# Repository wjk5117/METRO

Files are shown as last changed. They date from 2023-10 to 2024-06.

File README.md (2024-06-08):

# About
This directory contains all code implementation and hardware designs for METRO.

As a brief summary, road surface markings, like symbols and line markings, are vital
traffic infrastructures for driving safety and efficiency. However,
real-world conditions can impair the utility of existing road markings. For example, adverse weather conditions such as snow and
rain can quickly obliterate visibility.
Existing vision-free methods (e.g., mmWave, RFID) suffer from several key issues, such as
signal distortion due to the multi-path effect in high-speed scenarios
and high deployment costs. 

We propose a novel MagnETic ROad marking system (METRO)
for robust recognition of road markings at low cost and high deployability. METRO pairs (a) easily deployable passive magnetic road
markings with (b) an automotive-grade magnetic sensing framework that detects and interprets these markings. The design of
METRO addresses several real-world challenges, such as mitigating
the impact of magnetic disturbances, lowering deployment costs,
and enhancing the durability of magnetic tags. On-road field tests of
METRO demonstrate an overall accuracy of over 96% in interpreting
various road markings in adverse conditions with less cost (only
$0.17 per meter) than traditional road markings ($0.21-7.70 per meter). Our field evaluation of METRO over one month demonstrates
the practicality and robustness of METRO in real-world settings.

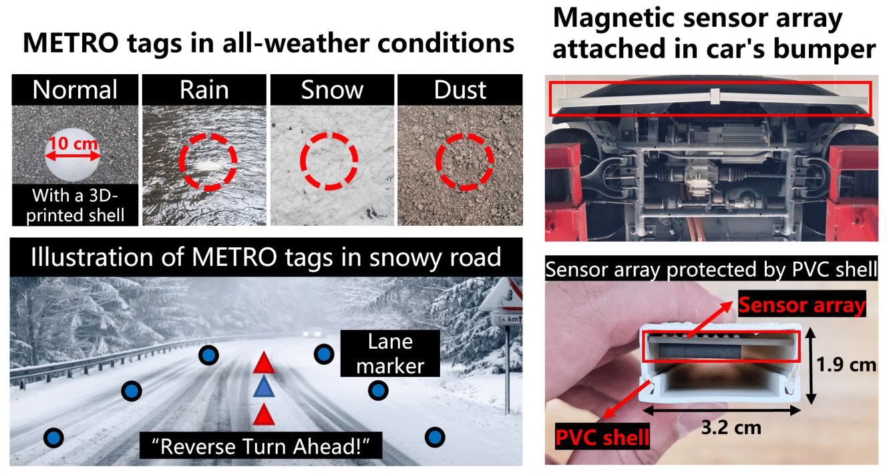
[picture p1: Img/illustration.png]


# Lisense
METRO is licensed under the MIT license included in the [LICENSE](./LICENSE) file.

# Setup
To use METRO, the following hardwares and development tools are required:
* [METRO's sensor array](#metros-sensor-array)
* [Arduino IDE](#arduino-ide-setup)
* [Python environment](#python-environment-setup)
* [PCAN-View](#connect-to-the-can-network)

## METRO's sensor array
We provide the manufacturing details of the METRO's sensor array in `/PCBs`, please see the related [README](./PCBs/README.md) file.

## Arduino IDE setup
Arduino IDE is used for programing the sensor array.

1. Download and install [Arduino IDE](https://www.arduino.cc/en/software)
2. Set up the Arduino IDE for the Teensy 4.1 Development Board, according to the [official instruction](https://www.pjrc.com/teensy/td_download.html).
Once completed, you will be able to access the board information by clicking on the 'Tools' menu
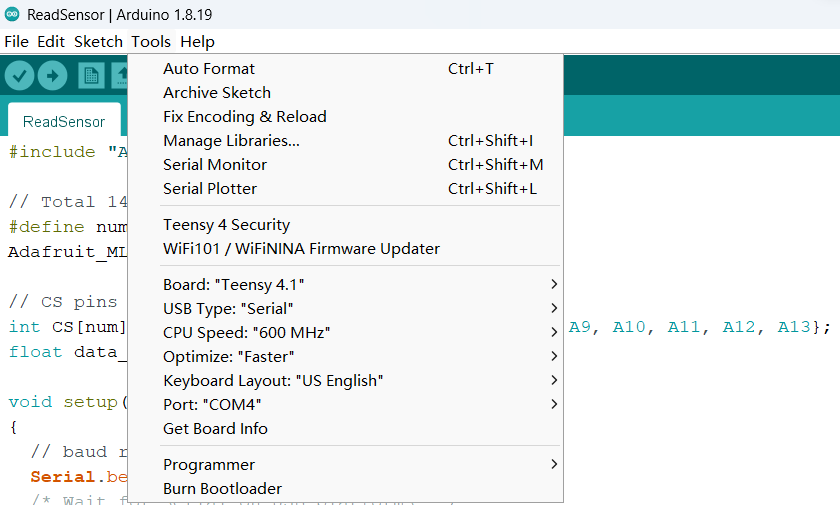
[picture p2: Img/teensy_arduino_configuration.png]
  

3. Install the Adafruit MLX90393 Library for the Arduino IDE:
    - Click 'Sketch' --> 'Include Library' --> 'Manage Libraries...'
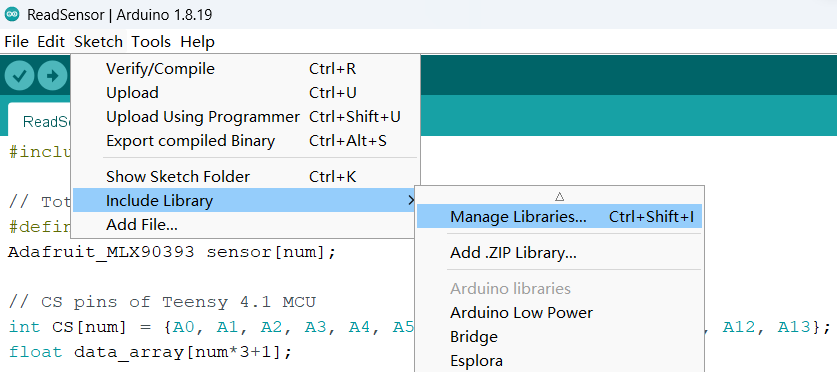
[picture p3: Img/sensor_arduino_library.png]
    
    - Search for Adafruit MLX90393, and install the Adafruit MLX90393 library:
    plot

## Python environment setup
The METRO system's sensing pipeline is developed using the Python programming language.

1. Install the Python environment. You can install the [official Python distribution](https://www.python.org/downloads/) or [Anaconda](https://www.anaconda.com/download)
2. Install all the dependencies listed in the `./Code/requirements.txt` file by using the command 'pip install \<package-name\>'.

## Connect to the CAN bus
To obtain velocity and steering angle data from the vehicle's Controller Area Network (CAN) bus,
a [PCAN-USB adapter](https://www.peak-system.com/PCAN-USB.199.0.html?&L=1) to connect to the vehicle and the official software [PCAN-View](https://www.peak-system.com/PCAN-View.242.0.html?&L=1) are required.

With these tools, you can connect to the CAN bus with the following Python script.
```python
import can
from can.bus import BusState
from can.interfaces.pcan.basic import *

BUS = can.interface.Bus(bustype="pcan",channel="PCAN_USBBUS1", bitrate=500000)
BUS.state = BusState.PASSIVE
```

Then, you can get the real-time data from the CAN network by running the following code.
```python
msg = BUS.recv(1)
```

The full implementation of obtaining velocity and steering angle data from the CAN network is integrated into the real-time sensing pipeline `Codes/Sensing_Pipeline/real_time_detecting_both_tag.py`. Please see lines 82-101 for more details.

# Run a Quick Demo
You can find a quick demo in the `/Quick_Demo` directory that does not require a connection to the vehicle's CAN network. For more information, please refer to the related [README](./Quick_Demo/README.md) file.

# Citing METRO
If you use METRO in your research or wish to refer to the baseline results, please use the provided BibTeX entry below.

```BibTex
@inproceedings{metro,
author = {Wang, Jike and Wang, Shanmu and Iravantchi, Yasha and Wang, Mingke and Sample, Alanson and Shin, Kang G. and Wang, Xinbing and Zhou, Chenghu and Chen, Dongyao},
title = {METRO: Magnetic Road Markings for All-weather, Smart Roads},
year = {2024},
isbn = {9798400704147},
publisher = {Association for Computing Machinery},
address = {New York, NY, USA},
url = {https://doi.org/10.1145/3625687.3625809},
doi = {10.1145/3625687.3625809},
booktitle = {Proceedings of the 21st ACM Conference on Embedded Networked Sensor Systems},
pages = {280–293},
numpages = {14},
keywords = {magnetic sensing, all-weather road markings, magnetometer},
location = {, Istanbul, Turkiye, },
series = {SenSys '23}
}
```

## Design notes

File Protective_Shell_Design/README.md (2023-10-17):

# 3D-printed Protective Shell Design for METRO Tags

## Description
This directory contains 3D-printed protective shell designs for the cubic passive magnet utilized in the METRO system
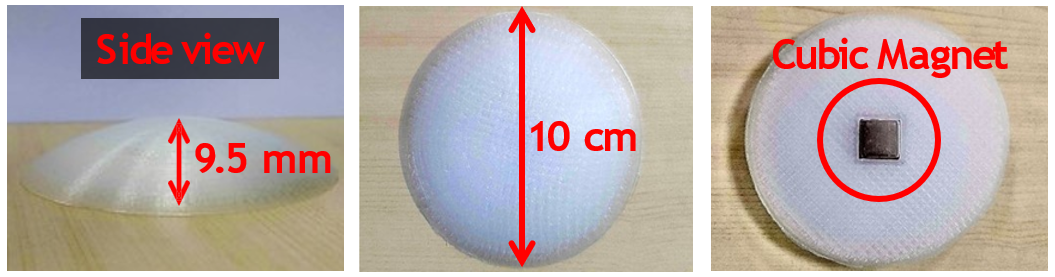
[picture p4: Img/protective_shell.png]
plot


We provide both STL (stereolithography) and G-code files for your convenience.

- line_tag.stl: The STL file for the protective shell designed for the 90-degree magnet.
- information_tag.stl: the STL file for the protective shell designed for the 0-degree magnet.
- gcode.zip: contains the G-code file for the protective shells designed for both the 90-degree magnet and 0-degree magnet.

## Design tool
We utilize [SolidWorks](https://www.solidworks.com/sw/support/downloads.htm) (version 2021) for designing all the STL files.
To convert these STL files into the G-code format, we use [Ultimaker Cura](https://ultimaker.com/software/ultimaker-cura/) (Version 5.4.0) and our 3D printer is [the Creality Ender-3 S1 Pro](https://www.creality.com/products/creality-ender-3-s1-pro-fdm-3d-printer).

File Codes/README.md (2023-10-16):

# Codes for METRO

## Arduino
- Library: Adafruit's library for the MLX90393 magnetic field sensor.
- ReadSensor: Capture time-series magnetic field data from the MLX90393 magnetometers and transmit it to the computing unit via a wired connection.

## Sensing_Pipeline
All codes for real-time detection and decoding of on-road magnetic tags.

- AMN_denoise.py: the implementation of the Adaptive Magnetic field Neutralization (AMN) algorithm to mitigate noise generated by wheel rotation.
- real_time_detecting_both_tag.py: connect to the CAN bus of a vehicle,then detect and decode both line and information tags in real time .
- real_time_detecting_info_tag.py: connect to the CAN bus of a vehicle,then detect and decode information tag in real time.
- utils.py: contains utility functions for the real-time detection process.

## Visualization
All codes for visualizing the experiment results.

## Requirements.txt
All Python package dependencies required for code execution.

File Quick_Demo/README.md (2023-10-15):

# Run a quick demo
This directory contains the code to run a quick demo of METRO.
This demo has been simplified to work without the need for a connection to the vehicle's CAN network. 

Specifically, the file `real_time_detecting_magnet.py` contains the sensing algorithm for detecting the N/S polarity of a 90-degree passive magnet.
To use this, you only need to manufacture the sensor array in  `../PCBs` and run the code using Python. 
With this setup, you can obtain real-time N/S polarity information as you move the passive magnet over the sensor array.

To ensure the correct execution of the code, please follow these steps:

1. Manufacture the sensor array based on the [README](../PCBs/README.md) file in `../PCBs`.
For the quick demo, you can only build the MCU and just one segment of the sensor array (e.g., "LeftBar1").

2. Compile and upload the `Codes/Arduino/ReadSensor/ReadSensor.ino` to the sensor array using the Arduino IDE.
Note that the default code is designed for use with a total of 14 MLX90393 magnetometers.  
You may need to adjust the number of MLX90393 sensors (line 4) and their respective chip select pins (line 8) to match the configuration of your specific sensor array.

3. Before running the `real_time_detecting_magnet.py`, you also need to replace the number of magnetometers used on line 31 and specify the serial port connection to the sensor array on line 35 to match your setup.

4. Run the `real_time_detecting_magnet.py` and move a passive magnet with a 90-degree polarity orientation (i.e., N-pole up or S-pole up) over the sensor array.
    - The default speed is set to 1.8 km/h (0.5 m/s), you can modify the speed parameter on line 48 as needed. 
    - By default, the code is capable of consistently detecting the N/S polarities of an N52-grade cubic magnet measuring 15 mm x 15 mm x 9.5 mm at a maximum height of ~30 cm. If you wish to use a smaller passive magnet or at a larger height, you can adjust the initial parameters and threshold settings within lines 41-51.

For the full implementation of the METRO system, you need to establish a connection to the CAN network of a vehicle and then execute the code provided in the `..Codes/Sensing_Pipeline` directory.

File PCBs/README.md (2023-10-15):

# PCB Design of METRO's Sensor Array

## Description
This directory contains the comprehensive PCB design for METRO's sensor array, including a sensor bar for on-road METRO tag detection and two reference sensors designed to mitigate wheel noise. 
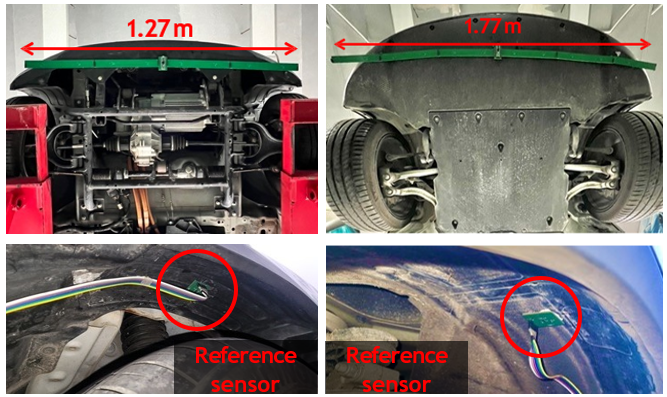
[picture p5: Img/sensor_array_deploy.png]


The size of the long sensor bar is 3.2 cm x 177.0 cm.
For better extensibility and mass production, we divide the sensor bar into six segments (i.e., "LeftBar1", "LeftBar2", "LeftBar3", "RightBar1", "RightBar2", "RightBar3").

Each reference sensor (i.e.,"Left_Ref_Sensor" and "Right_Ref_Sensor") has dimensions of 3.2 cm x 3.2 cm.

"MCU" refers to the PCB design of the Teensy 4.1 Microcontroller Development Board employed in the METRO system.

"Bom" refers to the bill of materials, which lists the necessary materials and components for constructing a sensor array.

## Assembly
Each segment of the long sensor bar is connected with a female and a U-shaped male 2.54mm pin header.
Two 24-pin female headers are welded to the MCU board to connect the Teensy 4.1 Controller Board.

## Curcuit Schematic
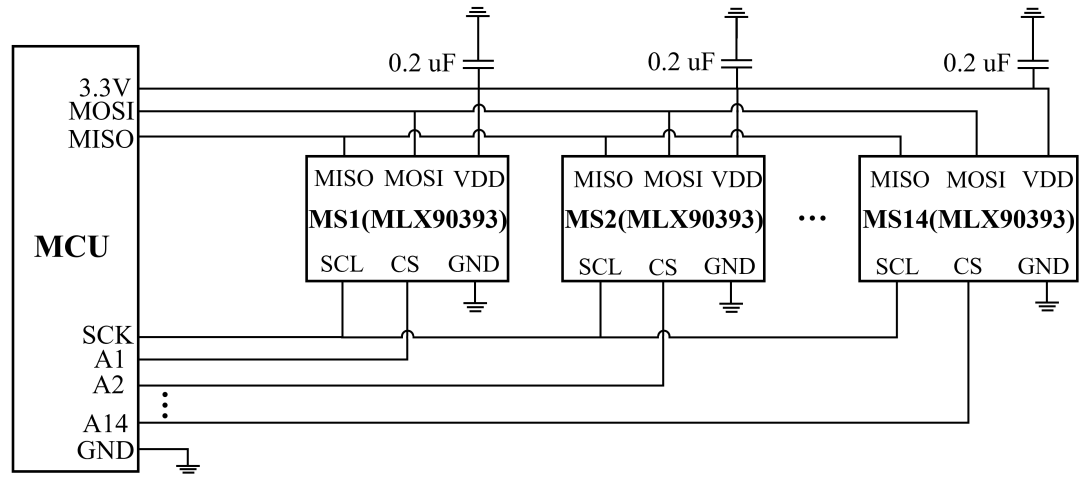
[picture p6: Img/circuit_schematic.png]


## Design Tool and Library
We utilize [Altium Designer](https://www.altium.com/altium-designer) (version 20.0.13) to design PCB boards.
The component library of capacitive and resistance relies on the standard library.
The footprint of the MLX90393 magnetometer we used, can see https://www.snapeda.com/parts/MLX90393SLW-ABA-011-RE/Melexis%20Technologies/view-part/551380/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

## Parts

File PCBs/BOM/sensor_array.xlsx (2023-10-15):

PCB | Comment | Description | Designator | Footprint | LibRef | Pins | Quantity
LeftBar1 | 0.1uF | Capacitance | CA0, CA0_2, CA1, CA1_2 | CAP_0603 | CAP | 2 | 4
 | 10k | Resistance | R1, R2 | RES_0603 | RES | 2 | 2
 | MLX90393SLW ABA 011 RE | MLX90393 Sensor | MS_A0, MS_A1 | MLX90393 | MLX90393SLW ABA 011 RE | 17 | 2
LeftBar2 | 0.1uF | Capacitance | CA2, CA2_2, CA3, CA3_2 | CAP_0603 | CAP | 2 | 4
 | MLX90393SLW ABA 011 RE | MLX90393 Sensor | MS_A2, MS_A3 | MLX90393 | MLX90393SLW ABA 011 RE | 17 | 2
LeftBar3 | 0.1uF | Capacitance | CA4, CA4_2, CA5, CA5_2 | CAP_0603 | CAP | 2 | 4
 | MLX90393SLW ABA 011 RE | MLX90393 Sensor | MS_A4, MS_A5 | MLX90393 | MLX90393SLW ABA 011 RE | 17 | 2
Left_Ref_Sensor | 0.1uF | Capacitance | C16, C16_2 | CAP_0603 | CAP | 2 | 2
 | MLX90393SLW ABA 011 RE | MLX90393 Sensor | MS_16 | MLX90393 | MLX90393SLW ABA 011 RE | 17 | 1
RightBar1 | 0.1uF | Capacitance | CSD, CSD_2, CSC, CSC_2 | CAP_0603 | CAP | 2 | 4
 | MLX90393SLW ABA 011 RE | MLX90393 Sensor | MS_SD, MS_SC | MLX90393 | MLX90393SLW ABA 011 RE | 17 | 2
RightBar2 | 0.1uF | Capacitance | C27, C27_2, C30, C30_2 | CAP_0603 | CAP | 2 | 4
 | MLX90393SLW ABA 011 RE | MLX90393 Sensor | MS_27, MS_30 | MLX90393 | MLX90393SLW ABA 011 RE | 17 | 2
RightBar3 | 0.1uF | Capacitance | C11, C11_2, C7, C7_2 | CAP_0603 | CAP | 2 | 4
 | MLX90393SLW ABA 011 RE | MLX90393 Sensor | MS_11, MS_7 | MLX90393 | MLX90393SLW ABA 011 RE | 17 | 2
Right_Ref_Sensor | 0.1uF | Capacitance | C15, C15_2 | CAP_0603 | CAP | 2 | 2
 | MLX90393SLW ABA 011 RE | MLX90393 Sensor | MS_15 | MLX90393 | MLX90393SLW ABA 011 RE | 17 | 1
MCU | Teensy | IC | Teensy | Teensy | Teensy | 48 | 1

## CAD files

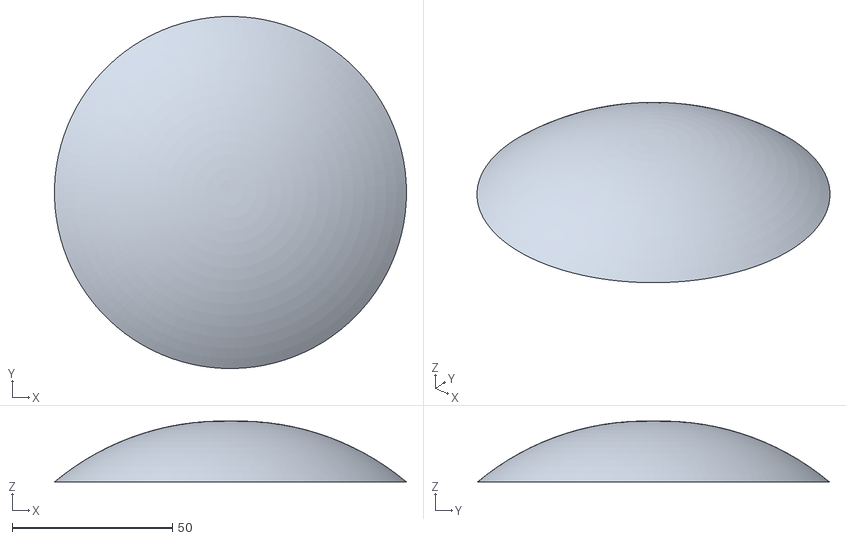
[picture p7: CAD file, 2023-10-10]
Protective_Shell_Design/information_tag.stl
110.0 x 110.0 x 19.0

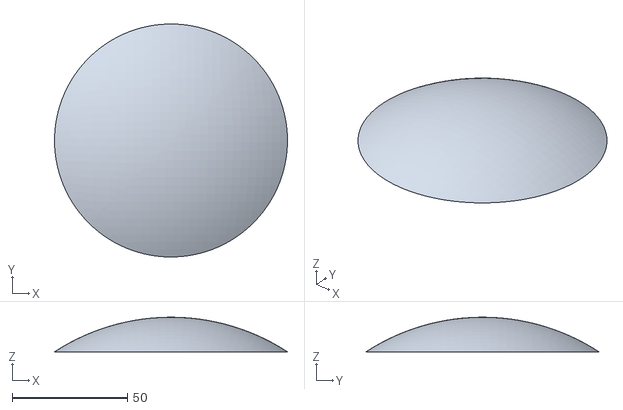
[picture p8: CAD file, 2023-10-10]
Protective_Shell_Design/line_tag.stl
101.0 x 101.0 x 15.0

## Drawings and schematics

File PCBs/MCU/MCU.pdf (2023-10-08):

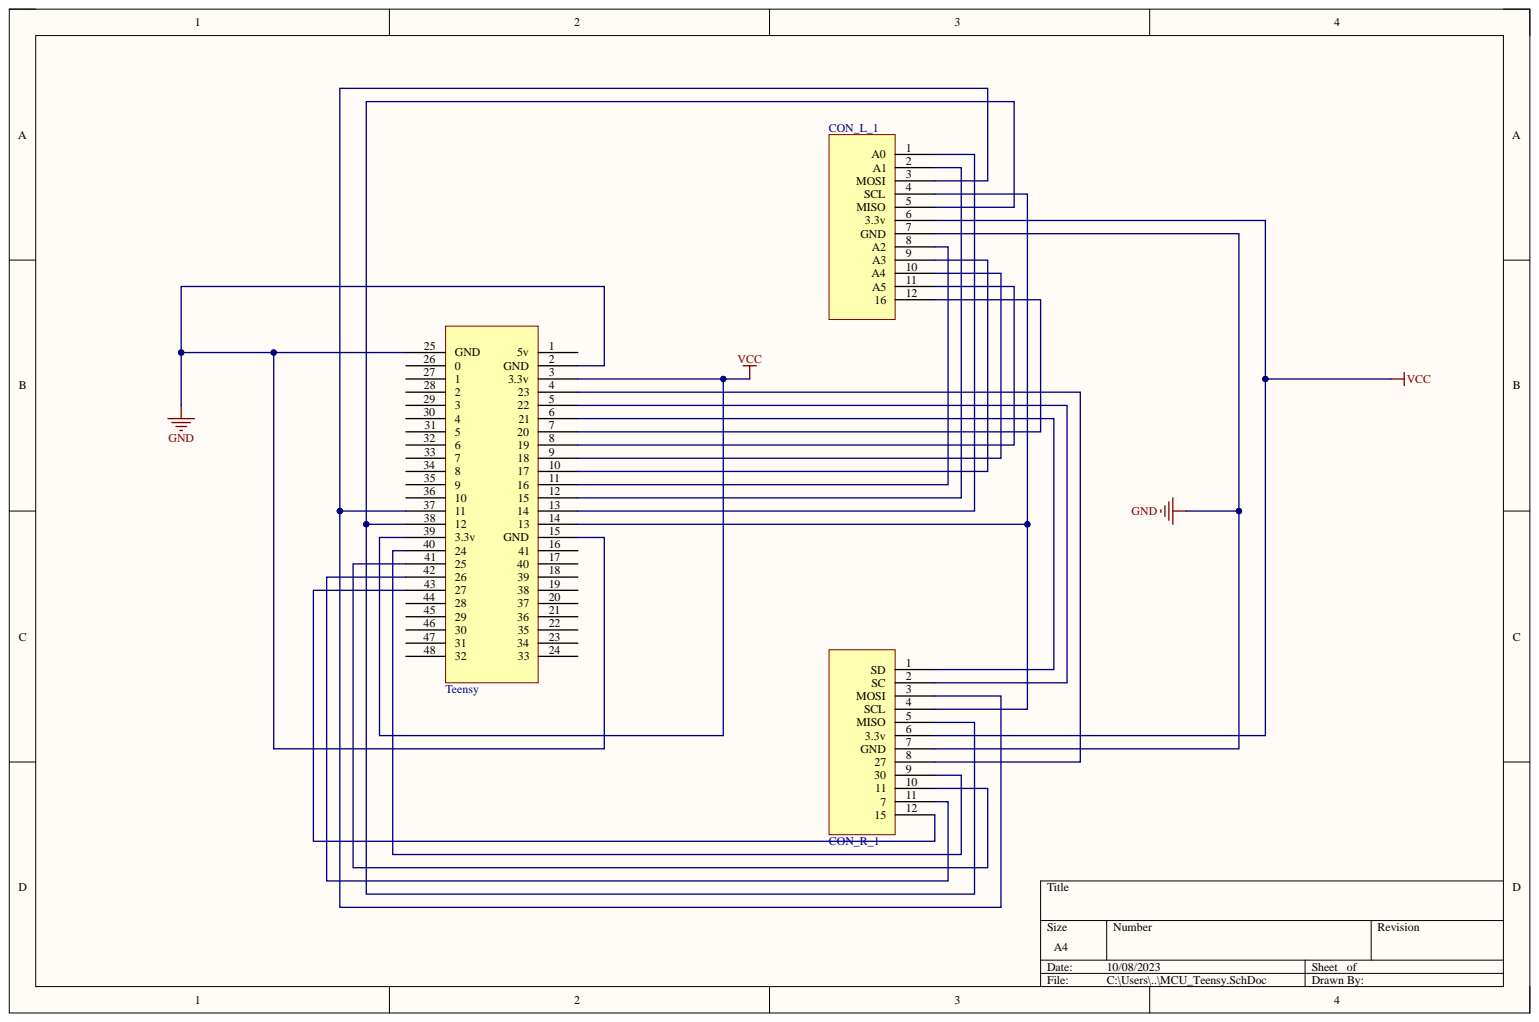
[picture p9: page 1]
Title; Size; Number; Revision; Date:; Sheet of; File:; C:\Users\..\MCU_Teensy.SchDoc; Drawn By:; GND 25; 16 GND; 3 GND; Teensy; SCL; GND; MOSI; MISO; CON_L_1; CON_R_1; VCC

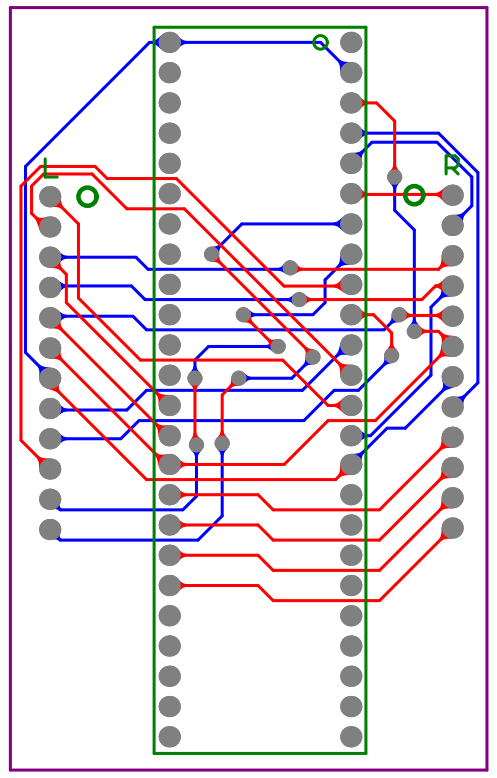
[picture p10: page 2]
PAL011; PAL010; PAL09; PAL08; PAL07; PAL06; PAL05; PAL04; PAL03; PAL02; PAL01; PAL012; COL; PAR01 PAR02 PAR03 PAR04 PAR05 PAR06 PAR07 PAR08 PAR09 PAR010 PAR011 PAR012; COR; PAR07; PAR08; PAR02; PAR01; PAR04; PAR03; PAR05; PAR09; PAR010; PAR011; PAR012; PAR06

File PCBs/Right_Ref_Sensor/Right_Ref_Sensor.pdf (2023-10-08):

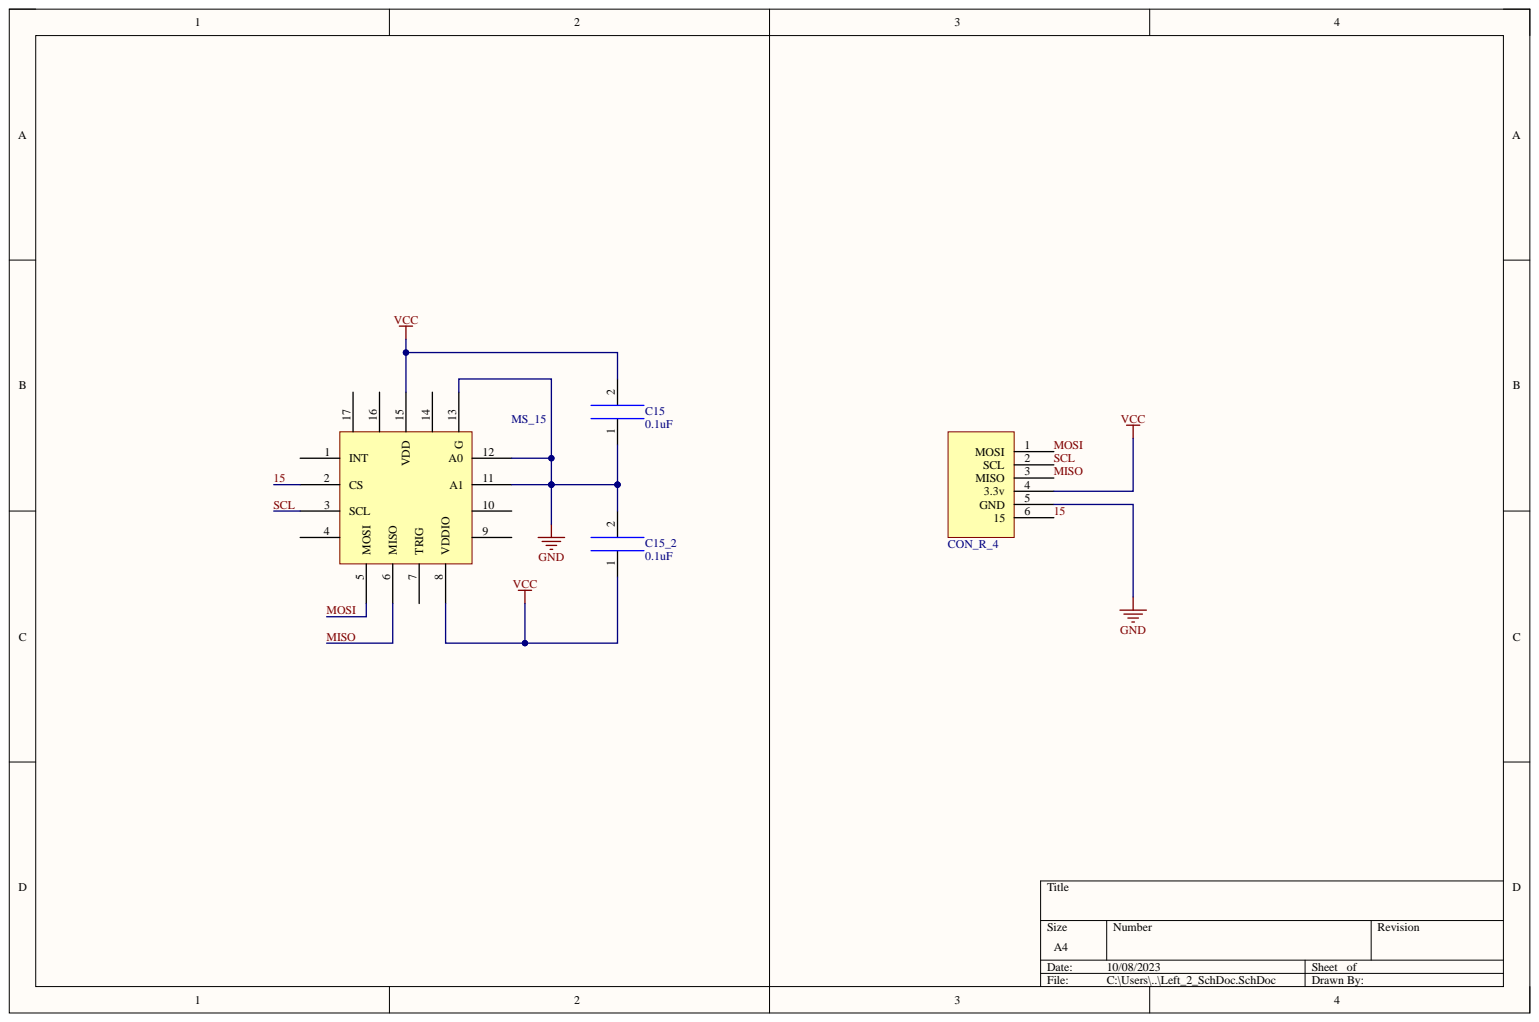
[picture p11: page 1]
Title; Size; Number; Revision; Date:; Sheet of; File:; C:\Users\..\Left_2_SchDoc.SchDoc; Drawn By:; INT 1; SCL 3; MOSI 5; MISO 6; TRIG 7; VDDIO 8; VDD 15; SCL; MOSI; MISO; VCC; GND; CON_R_4; MOSI SCL MISO

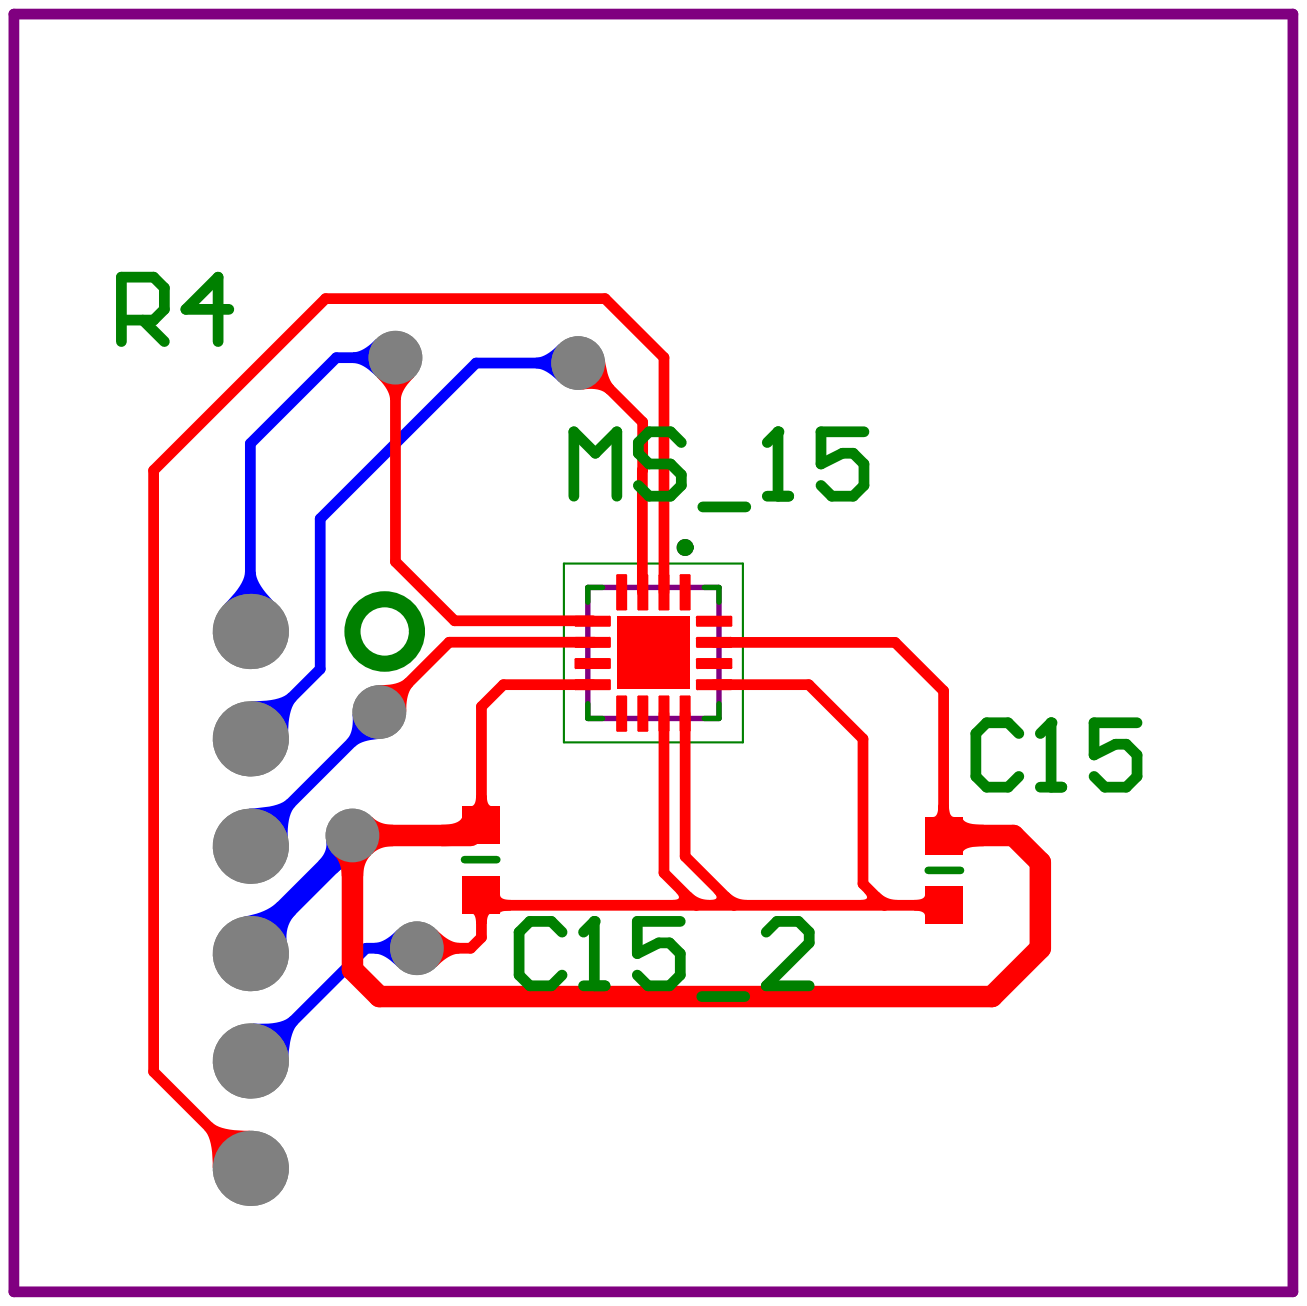
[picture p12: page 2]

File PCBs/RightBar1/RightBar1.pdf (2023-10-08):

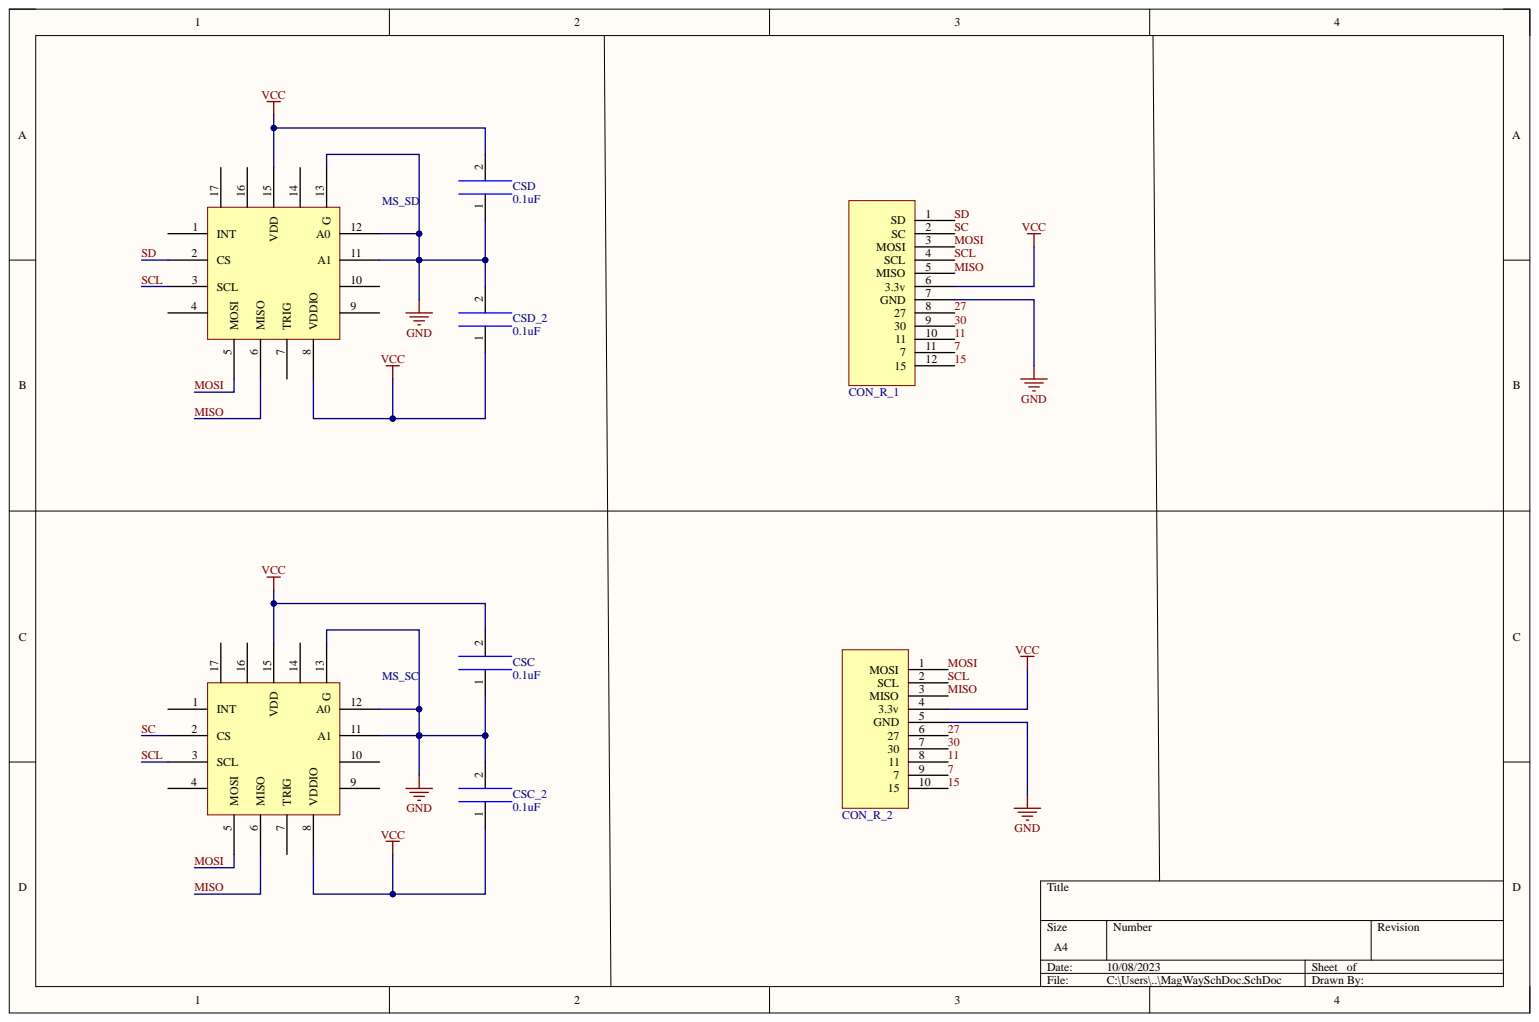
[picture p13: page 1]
Title; Size; Number; Revision; Date:; Sheet of; File:; C:\Users\..\MagWaySchDoc.SchDoc; Drawn By:; INT 1; SCL 3; MOSI 5; MISO 6; TRIG 7; VDDIO 8; VDD 15; VCC; GND; CSC 0.1uF; CSC_2 0.1uF; CSD 0.1uF; CSD_2 0.1uF; MISO; MOSI; SCL; CON_R_1; CON_R_2; SD SC MOSI SCL MISO; MOSI SCL MISO

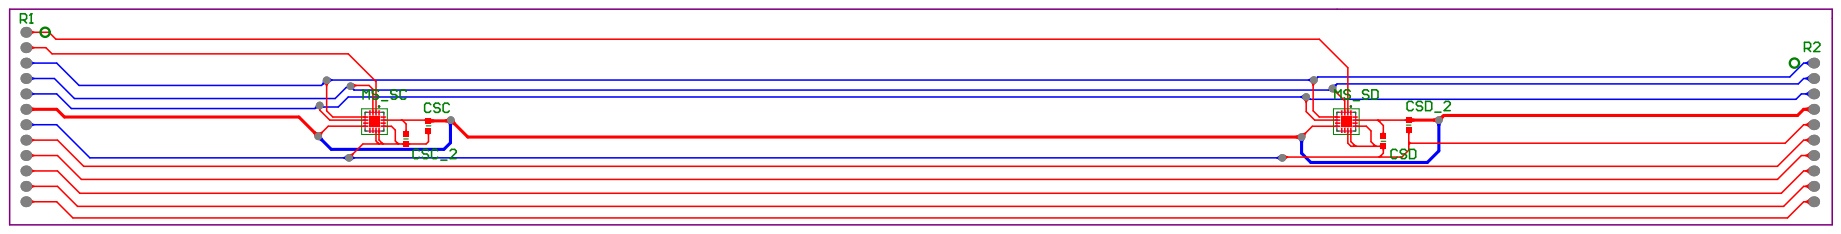
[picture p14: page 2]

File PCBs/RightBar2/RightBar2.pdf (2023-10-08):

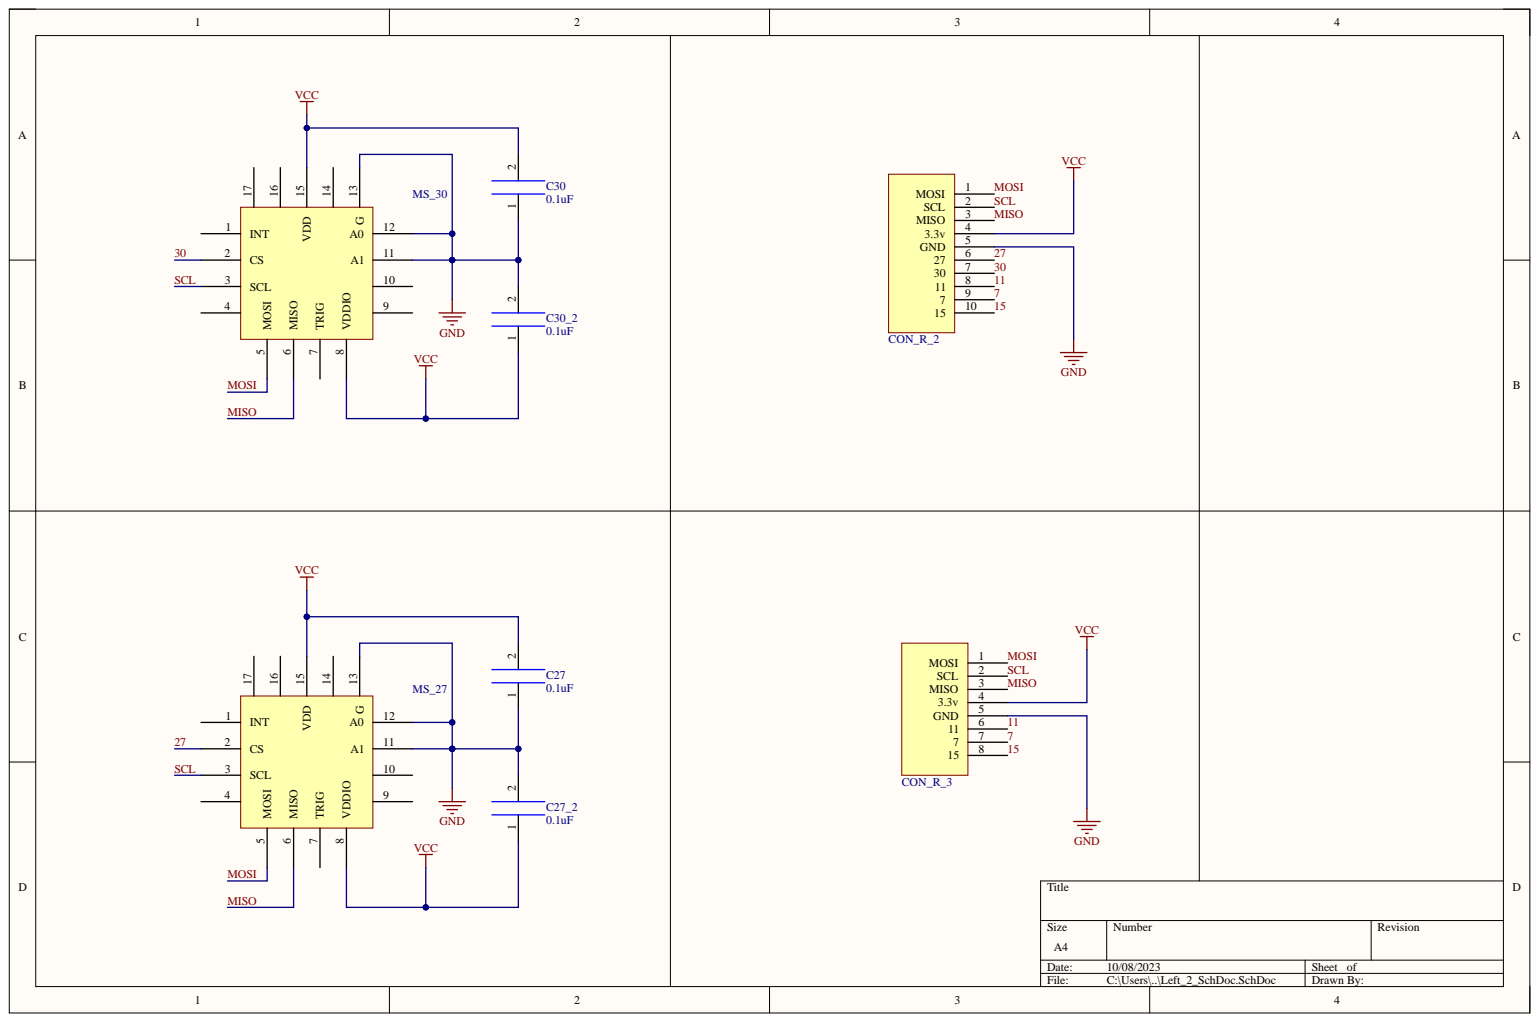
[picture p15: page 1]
Title; Size; Number; Revision; Date:; Sheet of; File:; C:\Users\..\Left_2_SchDoc.SchDoc; Drawn By:; INT 1; SCL 3; MOSI 5; MISO 6; TRIG 7; VDDIO 8; VDD 15; MOSI; GND; VCC; SCL; MISO; CON_R_2; CON_R_3; MOSI SCL MISO

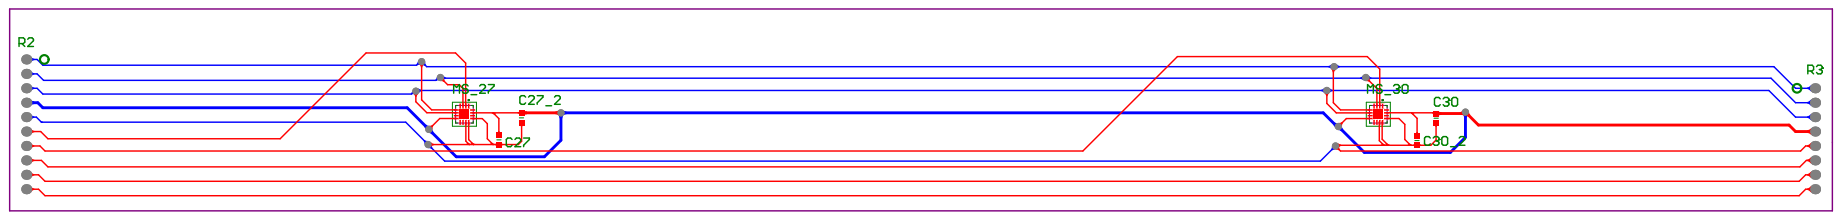
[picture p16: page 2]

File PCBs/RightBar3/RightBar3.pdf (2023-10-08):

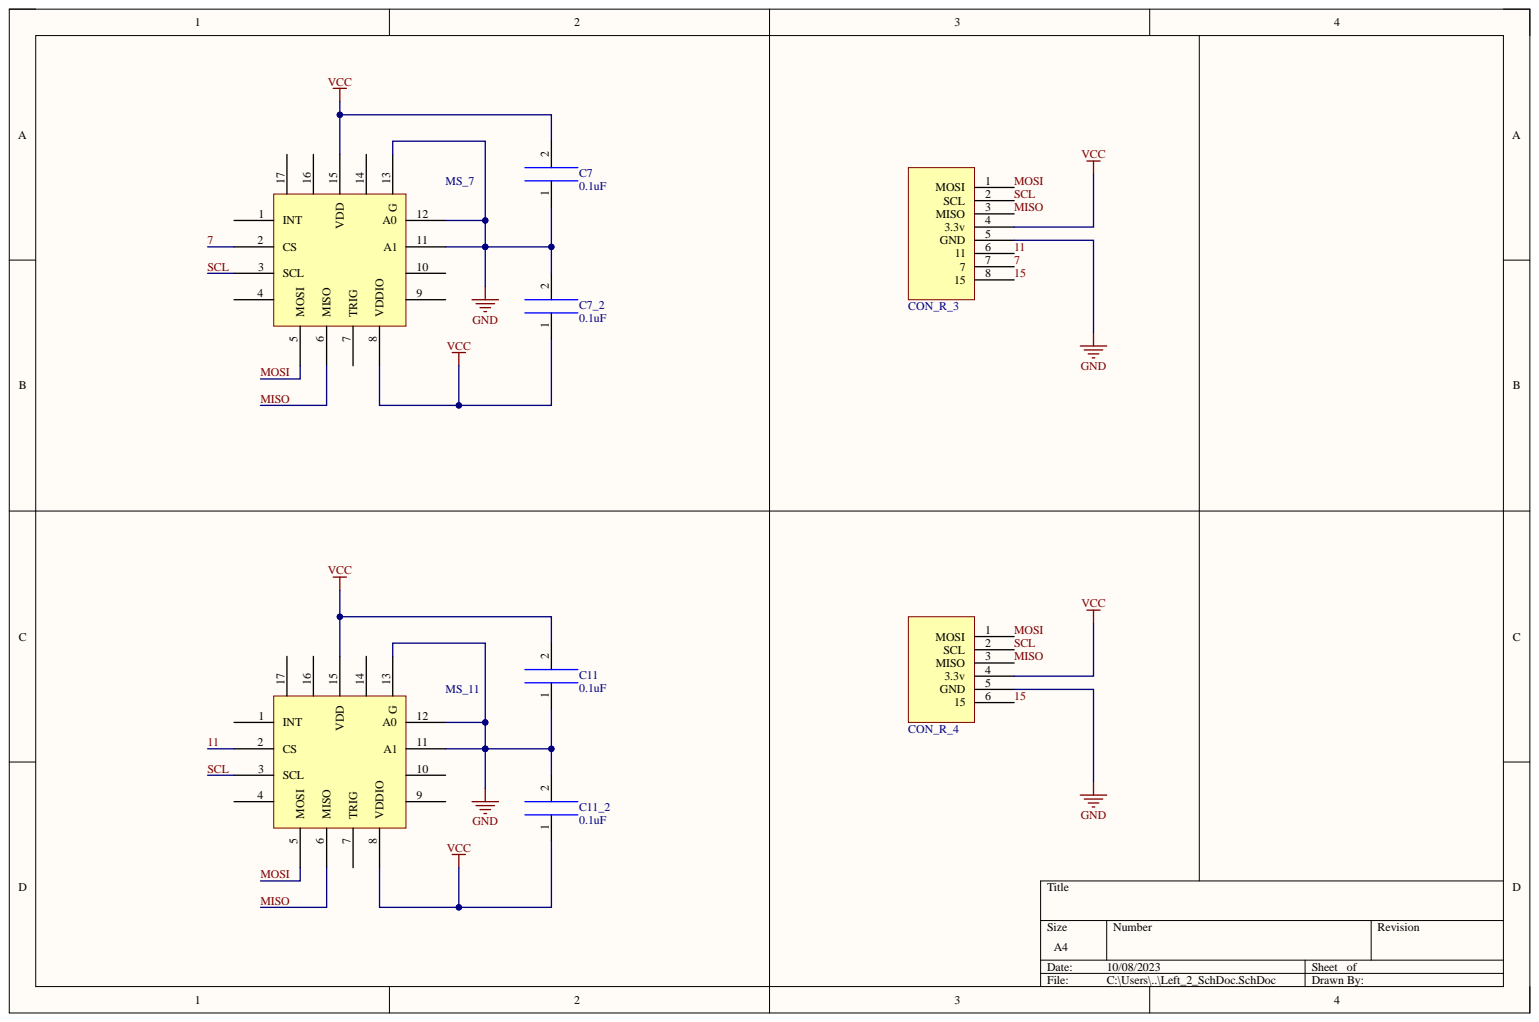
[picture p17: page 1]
Title; Size; Number; Revision; Date:; Sheet of; File:; C:\Users\..\Left_2_SchDoc.SchDoc; Drawn By:; INT 1; SCL 3; MOSI 5; MISO 6; TRIG 7; VDDIO 8; VDD 15; MOSI; GND; VCC; SCL; MISO; CON_R_3; CON_R_4; MOSI SCL MISO

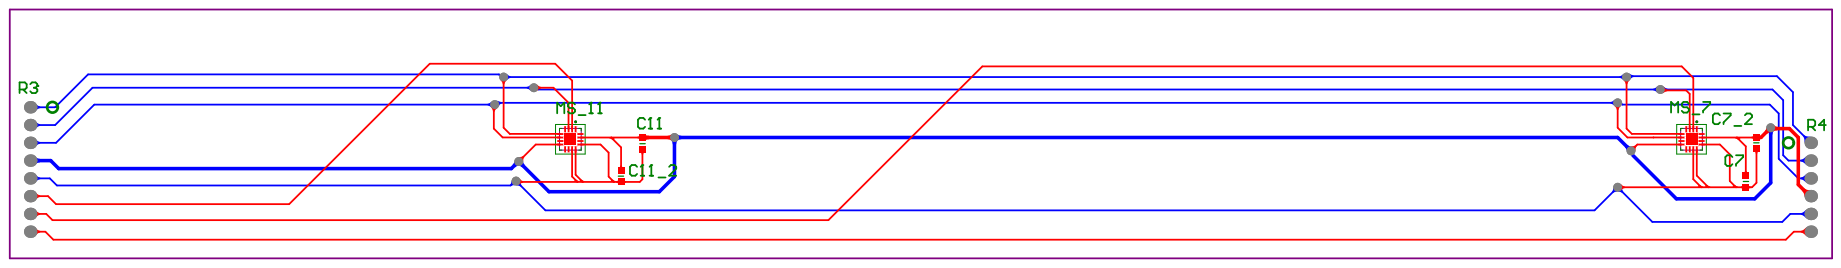
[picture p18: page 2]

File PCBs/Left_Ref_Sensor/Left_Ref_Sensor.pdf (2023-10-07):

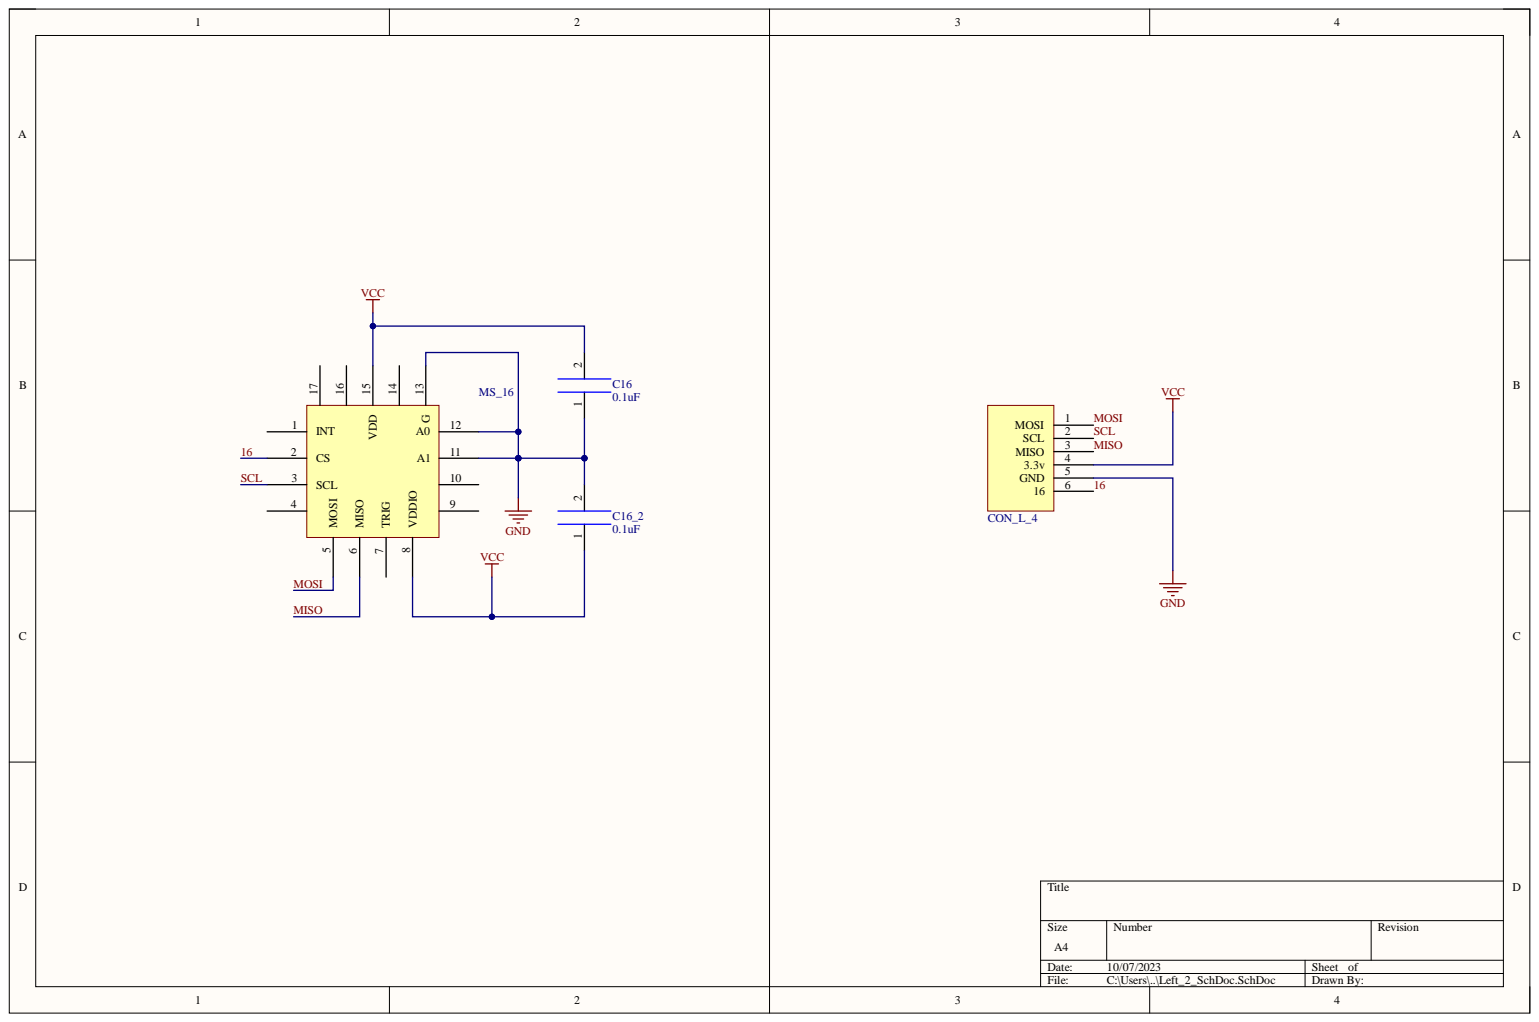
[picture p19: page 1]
Title; Size; Number; Revision; Date:; Sheet of; File:; C:\Users\..\Left_2_SchDoc.SchDoc; Drawn By:; INT 1; SCL 3; MOSI 5; MISO 6; TRIG 7; VDDIO 8; VDD 15; SCL; MOSI; MISO; VCC; GND; CON_L_4; MOSI SCL MISO

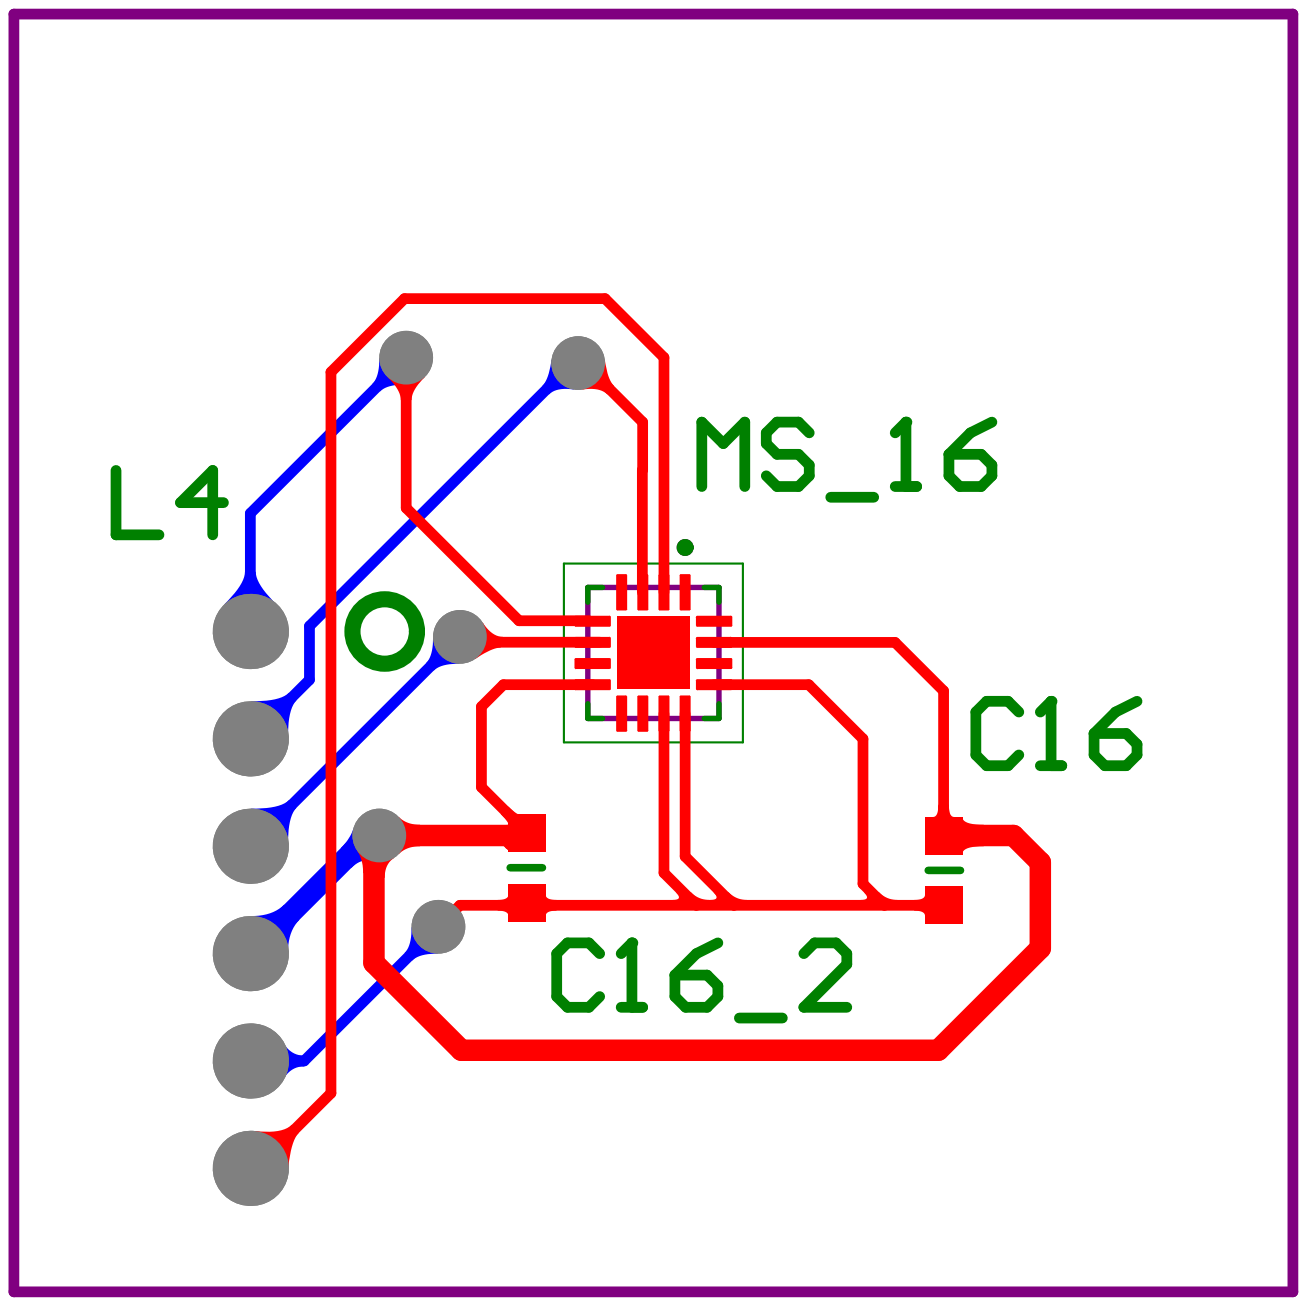
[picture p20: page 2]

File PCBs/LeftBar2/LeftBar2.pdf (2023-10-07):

Title; Size; Number; Revision; Date:; Sheet of; File:; C:\Users\..\Left_2_SchDoc.SchDoc; Drawn By:; INT 1; SCL 3; MOSI 5; MISO 6; TRIG 7; VDDIO 8; VDD 15; MISO; MOSI; GND; SCL; CON_L_2; PIN_left_2; VCC; MOSI SCL MISO; CON_L_3


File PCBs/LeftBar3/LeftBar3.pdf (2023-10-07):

Title; Size; Number; Revision; Date:; Sheet of; File:; C:\Users\..\Left_2_SchDoc.SchDoc; Drawn By:; INT 1; SCL 3; MOSI 5; MISO 6; TRIG 7; VDDIO 8; VDD 15; SCL; MOSI; MISO; VCC; GND; MOSI SCL; SCL MISO; CON_L_4; CON_L_3


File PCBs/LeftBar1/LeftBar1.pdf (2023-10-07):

Title; Size; Number; Revision; Date:; Sheet of; File:; C:\Users\..\MagWaySchDoc.SchDoc; Drawn By:; INT 1; SCL 3; MOSI 5; MISO 6; TRIG 7; VDDIO 8; VDD 15; MISO; MOSI; GND; SCL; CON_L_2; PIN_left_2; VCC; MOSI SCL MISO; CON_L_1; PIN_left; SCL MISO


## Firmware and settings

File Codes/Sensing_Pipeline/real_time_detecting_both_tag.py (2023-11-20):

'''
Detect both information and line tags
X-axis: used for detecting information tags (0-degree)
Z-axis: used for detecting line tags (90-degree)
'''
import multiprocessing as mp
import pandas as pd
import numpy as np
import datetime
import binascii
import serial
import struct
import time
import can

from can.bus import BusState
from can.interfaces.pcan.basic import *
from scipy.signal import savgol_filter
from AMN_denoise import *
from utils import *


# ------------Experiment Settings-------------
scenario = "Detecting_both_tag_"
cnt_exp = 1
# Number of sensors
num = 14
# experiment times
times = 1
# COM port for connecting Arduino
COM = 'COM11'


# ---------Initial Parameters and Thresholds---------
# These parameters and thresholds are empirically determined for the specific sensors used
# May need to finetune to optimize results if used different sensors
wnd = 15  # Gaussian Smoother for the raw signal data
wnd_d = 5  # Gaussian Smoother for the 1st derivative data
SG_wnd = 5 # Savgol filter window size
delta_thrd_x, delta_thrd_z = ([16] * num for _ in range(2))
amp_thrd_x, amp_thrd_z = ([1.5] * num for _ in range(2))
# Speed info: km/h
default_speed = 10
cur_speed = 20
# Time threshold to eliminate the duplicate detection of 
# the same magnet from two adjacent sensors
delta_t = 0.0025 * 50 * default_speed / cur_speed


# Constants and Globals
raw_result = []
raw_name = ['Time Stamp'] + ['Sensor ' + str(i) for i in range(1, num + 1)]
no_x, no_z = 0, 0  # total number of peaks
n = 0  # index for the data points

x, sx, dx, sdx, z, sz, dz, sdz = ([[] for _ in range(num)] for _ in range(8))
slope_list_x, slope_list_z, raw_list_x, raw_list_z = ([[] for _ in range(num)] for _ in range(4))
slope_thrd_x, slope_thrd_z = ([10000] * num for _ in range(2))
estimate_x, estimate_z = ([True] * num for _ in range(2))
LastRAW_x, LastRAW_z = ([0] * num for _ in range(2))  # Record the time of last peak
N_flag_x, S_flag_x, N_flag_z, S_flag_z = ([0] * num for _ in range(4))



# def gaussian(x, pos, wid):
#     g = np.exp(-((x - pos) / (0.60056120439323 * wid)) ** 2)
#     return g
SmoothVector_r = gaussian(np.arange(wnd + 1)[1:], wnd / 2, wnd / 2)
SmoothVector_r = SmoothVector_r / (np.sum(SmoothVector_r))
SmoothVector_d = gaussian(np.arange(wnd_d + 1)[1:], wnd_d / 2, wnd_d / 2)
SmoothVector_d = SmoothVector_d / (np.sum(SmoothVector_d))
sensors = np.zeros((num, 3))

data = bytearray(4 * (3 * num + 1))
cnt = 1
current = 0

tag_x = []
cnt_mag = 0
speed_list, angle_list = [], []
# For denoising wheel noise
denoise_list_lx, denoise_list_ly, denoise_list_lz, denoise_list_rx, denoise_list_ry, denoise_list_rz = ([] for _ in range(6))
ref_list_lx, ref_list_ly, ref_list_lz, ref_list_rx, ref_list_ry, ref_list_rz = ([] for _ in range(6))


# Get velocity and steering wheel angle data (SWA) from CAN Bus
def read_Speed_SWA(listFrames, listFrames2):
    BUS = can.interface.Bus(bustype="pcan", channel="PCAN_USBBUS1", bitrate=500000)
    BUS.state = BusState.PASSIVE
    while True:
        msg = BUS.recv(1)
        if msg is not None:
            # CAN ID of the testing EV's speed data : 036A
            if msg.arbitration_id == int('036a', 16):
                bin_data = binascii.hexlify(msg.data)[8:12].decode("utf-8")
                if bin_data[0] == '3':
                    listFrames.append([msg.timestamp * 1000 * 1000, 0.0])
                else:
                    # Decode the speed data
                    listFrames.append([msg.timestamp * 1000 * 1000, int(bin_data[1] + bin_data[2:], 16) / 64])

            # CAN ID of the testing EV's SWA data: 0704
            if msg.arbitration_id == int('0704', 16):
                bin_data = binascii.hexlify(msg.data)[2:6].decode("utf-8")
                # Decode the SWA data
                listFrames2.append([msg.timestamp * 1000 * 1000, (int(bin_data, 16) - 9650) * 0.1 / 9.65])


# Detect the magnet in real time
def detectMag(listFrames, listFrames2):
    print("Begin detecting at", str(datetime.datetime.now()))
    arduino = serial.Serial(port=COM, baudrate=921600, timeout=None)
    arduino.flushInput()
    t = []
    global cnt, current, no_x, no_z, n_x, n, cnt_mag, cnt_exp, x, z, sx, sz, dx, dz, sdx, sdz, LastRAW_x, LastRAW_z
    global slope_thrd_x, slope_thrd_z, slope_list_x, slope_list_z, estimate_x, estimate_z, raw_result, raw_list_x, raw_list_z
    global speed_list, angle_list, delta_t
    global denoise_list_lx, denoise_list_ly, denoise_list_lz, denoise_list_rx, denoise_list_ry, denoise_list_rz
    global ref_list_lx, ref_list_ly, ref_list_lz, ref_list_rx, ref_list_ry, ref_list_rz
    try:
        while True:
            arduino.readinto(data)
            if cnt > 1000:  # discard headers
                if listFrames[-1][1] != 0:
                    # Update the time threshold according to the current speed
                    delta_t = 0.0025 * 50 * default_speed / listFrames[-1][1]
                    raw_result_tmp = [current]
                for i in range(num):
                    sensors[i, 0], = struct.unpack('f', data[(i * 12):(4 + i * 12)])
                    sensors[i, 1], = struct.unpack('f', data[(i * 12 + 4):(8 + i * 12)])
                    sensors[i, 2], = struct.unpack('f', data[(i * 12 + 8):(12 + i * 12)])
                    raw_result_tmp.append((sensors[i, 0], sensors[i, 1], sensors[i, 2]))
                raw_result.append(raw_result_tmp)
                speed_list.append([current, listFrames[-1][1]])
                angle_list.append([current, listFrames2[-1][1]])
                t.append(current)
                interval, = struct.unpack('f', data[(12 * num):(4 + 12 * num)])
                current += interval / 1000 / 1000
                
                '''
                Denoise the wheel noise with a slide window of 50 points, step size = 1 point
                '''
                # default left front sensor: sensor 6 (index 5)
                # default left reference sensor: sensor 7 (index 6)
                denoise_list_lx.append(sensors[5, 0])
                ref_list_lx.append(sensors[6, 0])
                denoise_list_ly.append(sensors[5, 1])
                ref_list_ly.append(sensors[6, 1])
                denoise_list_lz.append(sensors[5, 2])
                ref_list_lz.append(sensors[6, 2])

                # default right front sensor: sensor 13 (index 12)
                # default right reference sensor: sensor 14 (index 13)
                denoise_list_rx.append(sensors[12, 0])
                ref_list_rx.append(sensors[13, 0])
                denoise_list_ry.append(sensors[12, 1])
                ref_list_ry.append(sensors[13, 1])
                denoise_list_rz.append(sensors[12, 2])
                ref_list_rz.append(sensors[13, 2])

                if len(denoise_list_lx) == 50:
                    # denoise left front sensor data
                    denoised_lx, denoised_ly, denoised_lz = real_time_LMS(denoise_list_lx, denoise_list_ly, denoise_list_lz, ref_list_lx, ref_list_ly, ref_list_lz)
                    # denoise right front sensor data
                    denoised_rx, denoised_ry, denoised_rz = real_time_LMS(denoise_list_rx, denoise_list_ry, denoise_list_rz, ref_list_rx, ref_list_ry, ref_list_rz)

                    # update the denoised data
                    sensors[5, 0], sensors[5, 1], sensors[5, 2] = denoised_lx[-1], denoised_ly[-1], denoised_lz[-1]
                    # denoised right front sensor data
                    sensors[12, 0], sensors[12, 1], sensors[12, 2] = denoised_rx[-1], denoised_ry[-1], denoised_rz[-1]
        
                    # update the denoise and reference list
                    denoise_list_lx, denoise_list_ly, denoise_list_lz = denoise_list_lx[1:], denoise_list_ly[1:], denoise_list_lz[1:]
                    denoise_list_rx, denoise_list_ry, denoise_list_rz = denoise_list_rx[1:], denoise_list_ry[1:], denoise_list_rz[1:]
                    ref_list_lx, ref_list_ly, ref_list_lz = ref_list_lx[1:], ref_list_ly[1:], ref_list_lz[1:]
                    ref_list_rx, ref_list_ry, ref_list_rz = ref_list_rx[1:], ref_list_ry[1:], ref_list_rz[1:]


                for i in range(num):
                    z[i].append(sensors[i, 2])
                    x[i].append(sensors[i, 0])
                    
                # buffer x-axis and z-axis data before starting the detection
                if n <= max(wnd, SG_wnd):
                    for i in range(num):
                        sx[i].append(sensors[i, 0])
                        dx[i].append(0)
                        sdx[i].append(0)

                        sz[i].append(sensors[i, 2])
                        dz[i].append(0)
                        sdz[i].append(0)
                    n += 1
                    continue

                # Smoothing the raw data
                for i in range(num):
                    sx[i].append(np.sum(SmoothVector_r * (np.array(x[i][-wnd:]))))
                    sz[i].append(np.sum(SmoothVector_r * (np.array(z[i][-wnd:]))))

                # Savitzky–Golay filter for 1st derivative
                for i in range(num):
                    filtered = savgol_filter(sx[i][-SG_wnd:], SG_wnd, 5, deriv=1)
                    dx[i].append(filtered[(SG_wnd - 1) // 2])  # avoid boundary effect
                    
                    filtered_z = savgol_filter(sz[i][-SG_wnd:], SG_wnd, 1, deriv=1)
                    dz[i].append(filtered_z[(SG_wnd - 1) // 2])  # avoid boundary effect

                # smooth the 1st derivative
                for i in range(num):
                    sdx[i].append(np.sum(SmoothVector_d * (np.array(dx[i][-wnd_d:]))))
                    sdz[i].append(np.sum(SmoothVector_d * (np.array(dz[i][-wnd_d:]))))

                '''
                Detect the infomaion tag, x-axis data
                '''
                for i in range(num):
                    N_flag_x[i] = 0
                    S_flag_x[i] = 0
                    if len(slope_list_x[i]) == 50:
                        if estimate_x[i]:
                            slope_thrd_x[i] = amp_thrd_x[i] * np.abs(np.array(slope_list_x[i][1:])).max()
                            print('X axis of sensor %d: Pre-done with slope threshold equaling to %.2f' % (
                                i + 1, slope_thrd_x[i]))
                            delta_time = (t[n] - t[n - 50]) / 50
                            print('Sampling rate: %.2f Hz' % (1 / delta_time))
                            estimate_x[i] = False
                            Last_x = str(datetime.datetime.now())

                    # Detect the N polarity
                    if sdx[i][-1] > 0 and sdx[i][-2] <= 0:
                        slope_x = (sdx[i][-1] - sdx[i][-2])
                        slope_list_x[i].append(slope_x)
                        raw_x = sx[i][n - int((wnd + 1) / 2)]
                        raw_list_x[i].append(raw_x)
                        if slope_x >= slope_thrd_x[i]:
                            if LastRAW_x[i] == 0:
                                Now_x = str(datetime.datetime.now())
                                t_interval_x = getInterval(Last_x, Now_x)
                                if t_interval_x > delta_t:
                                    N_flag_x[i] = 1
                                    Last_x = Now_x
                                # no = no + 1
                                # print('Sensor %d: No. %d detect a N' % (i+1, no))

                            else:
                                if raw_x - LastRAW_x[i] <= -delta_thrd_x[i]:
                                    Now_x = str(datetime.datetime.now())
                                    t_interval_x = getInterval(Last_x, Now_x)
                                    if t_interval_x > delta_t:
                                        N_flag_x[i] = 1
                                        Last_x = Now_x
                                    # no = no + 1
                                    # print('Sensor %d: No. %d detect a N' % (i+1, no))
                        else:
                            LastRAW_x[i] = raw_x

                    # Detect the S polarity
                    if sdx[i][-1] < 0 and sdx[i][-2] >= 0:
                        slope_x = (sdx[i][-1] - sdx[i][-2])
                        slope_list_x[i].append(slope_x)
                        raw_x = sx[i][n - int((wnd + 1) / 2)]
                        raw_list_x[i].append(raw_x)
                        if slope_x <= -slope_thrd_x[i]:
                            if LastRAW_x[i] == 0:
                                Now_x = str(datetime.datetime.now())
                                t_interval_x = getInterval(Last_x, Now_x)
                                if t_interval_x > delta_t:
                                    S_flag_x[i] = 1
                                    Last_x = Now_x
                                # no = no + 1
                                # print('Sensor %d: No. %d detect a S' % (i+1, no))
                            else:
                                if raw_x - LastRAW_x[i] >= delta_thrd_x[i]:
                                    Now_x = str(datetime.datetime.now())
                                    t_interval_x = getInterval(Last_x, Now_x)
                                    if t_interval_x > delta_t:
                                        S_flag_x[i] = 1
                                        Last_x = Now_x
                                    # no = no + 1
                                    # print('Sensor %d: No. %d detect a S' % (i+1, no))
                        else:
                            LastRAW_x[i] = raw_x

                    file1 = open("results.txt", "a")
                    if np.sum(np.array(N_flag_x)) > 0:
                        # record tag start
                        no_x += 1
                        # speed, angle = listFrames[-1][1], listFrames2[-1][1]
                        print(str(datetime.datetime.now()) + ":", "speed is " + str(speed_list[-1][1]) + ";",
                              "SWA is " + str(angle_list[-1][1]) + ";", 'x axis detects No. %d N;' % no_x,
                              "peak index is " + str(cnt) + '\n')
                        file1.write(str(datetime.datetime.now()) + ": speed is " + str(
                            speed_list[-1][1]) + "; " + "SWA is " + str(
                            angle_list[-1][1]) + "; x axis detects No." + str(no_x) + " N; " + "peak index is " + str(
                            cnt) + '\n')
                        t1 = time.time() * 1000 * 1000
                        tag_x.append([cnt_mag, cnt, "N", speed_list[-1][1], angle_list[-1][1]])
                        cnt_mag += 1
                        # Tag prototype consists of 3 magnets
                        if cnt_mag == 3:
                            print("Tag info:", tag_x)
                            # calculate the distance ratio of the tag
                            calculate_ratio(tag_x, t1, delta_time, speed_list, angle_list)
                            cnt_mag = 0
                            tag_x.clear()

                    if np.sum(np.array(S_flag_x)) > 0:
                        no_x += 1
                        print(str(datetime.datetime.now()) + ":", "speed is " + str(speed_list[-1][1]) + ";",
                              "SWA is " + str(angle_list[-1][1]), 'x axis detects No. %d S polarity;' % no_x,
                              "peak index is " + str(cnt) + '\n')
                        file1.write(str(datetime.datetime.now()) + ": speed is " + str(
                            speed_list[-1][1]) + "; " + "SWA is " + str(
                            angle_list[-1][1]) + "; x axis detects No." + str(no_x) + " S; " + "peak index is " + str(
                            cnt) + '\n')
                        t1 = time.time() * 1000 * 1000
                        tag_x.append([cnt_mag, cnt, "S", speed_list[-1][1], angle_list[-1][1]])
                        cnt_mag += 1
                        # Tag prototype consists of 3 magnets
                        if cnt_mag == 3:
                            print("Tag info:", tag_x)
                            calculate_ratio(tag_x, t1, delta_time, speed_list, angle_list)
                            cnt_mag = 0
                            tag_x.clear()


                '''
                Detect the line tag, z-axis data
                '''
                for i in range(num):
                    N_flag_z[i] = 0
                    S_flag_z[i] = 0
                    if len(slope_list_z[i]) == 50:
                        if estimate_z[i]:
                            slope_thrd_z[i] = amp_thrd_z[i] * np.abs(np.array(slope_list_z[i][1:])).max()
                            print('X axis of sensor %d: Pre-done with slope threshold equaling to %.2f' % (
                                i + 1, slope_thrd_z[i]))
                            delta_time = (t[n] - t[n - 50]) / 50
                            print('Sampling rate: %.2f Hz' % (1 / delta_time))
                            estimate_z[i] = False
                            Last_z = str(datetime.datetime.now())

                    # Detect the N polarity
                    if sdz[i][-1] > 0 and sdz[i][-2] <= 0:
                        slope_z = (sdz[i][-1] - sdz[i][-2])
                        slope_list_z[i].append(slope_z)
                        raw_z = sz[i][n - int((wnd + 1) / 2)]
                        raw_list_z[i].append(raw_z)
                        if slope_z >= slope_thrd_z[i]:
                            if LastRAW_z[i] == 0:
                                Now_z = str(datetime.datetime.now())
                                t_interval_z = getInterval(Last_z, Now_z)
                                if t_interval_z > delta_t:
                                    N_flag_z[i] = 1
                                    Last_z = Now_z
                                # no = no + 1
                                # print('Sensor %d: No. %d detect a N' % (i+1, no))

                            else:
                                if raw_z - LastRAW_z[i] <= -delta_thrd_z[i]:
                                    Now_z = str(datetime.datetime.now())
                                    t_interval_z = getInterval(Last_z, Now_z)
                                    if t_interval_z > delta_t:
                                        N_flag_z[i] = 1
                                        Last_z = Now_z
                                    # no = no + 1
                                    # print('Sensor %d: No. %d detect a N' % (i+1, no))
                        else:
                            LastRAW_z[i] = raw_z

                    # Detect the S polarity
                    if sdz[i][-1] < 0 and sdz[i][-2] >= 0:
                        slope_z = (sdz[i][-1] - sdz[i][-2])
                        slope_list_z[i].append(slope_z)
                        raw_z = sz[i][n - int((wnd + 1) / 2)]
                        raw_list_z[i].append(raw_z)
                        if slope_z <= -slope_thrd_z[i]:
                            if LastRAW_z[i] == 0:
                                Now_z = str(datetime.datetime.now())
                                t_interval_z = getInterval(Last_z, Now_z)
                                if t_interval_z > delta_t:
                                    S_flag_z[i] = 1
                                    Last_z = Now_z
                                # no = no + 1
                                # print('Sensor %d: No. %d detect a S' % (i+1, no))
                            else:
                                if raw_z - LastRAW_z[i] >= delta_thrd_z[i]:
                                    Now_z = str(datetime.datetime.now())
                                    t_interval_z = getInterval(Last_z, Now_z)
                                    if t_interval_z > delta_t:
                                        S_flag_z[i] = 1
                                        Last_z = Now_z
                                    # no = no + 1
                                    # print('Sensor %d: No. %d detect a S' % (i+1, no))
                        else:
                            LastRAW_z[i] = raw_z

                    if np.sum(np.array(N_flag_z)) > 0:
                        print("Detect the N polarity of 90-degree magnet")
                        print("Warning lane departure from the solid line!")
                    
                    if np.sum*np.array(S_flag_z) > 0:
                        print("Detect the S polarity of 90-degree magnet")
                        print("Warning lane departure from the dashed line!")

                n = n + 1
            cnt += 1


    except KeyboardInterrupt:
        # Record the data
        print("Output csv")
        test = pd.DataFrame(columns=raw_name, data=raw_result)
        # Raw data
        test.to_csv("RawData_" + scenario + "_" + str(cur_speed) + "kmh_" + str(times) + ".csv")
        test_x = pd.DataFrame(columns=["THR_X"], data=slope_thrd_x)
        test_z = pd.DataFrame(columns=["THR_Z"], data=slope_thrd_z)
        # Thresholds
        test_x.to_csv("THR_X_" + scenario + "_" + str(cur_speed) + "kmh_" + str(times) + ".csv")
        test_z.to_csv("THR_Z_" + scenario + "_" + str(cur_speed) + "kmh_" + str(times) + ".csv")
        # Raw speed and SWA data
        test_speed = pd.DataFrame(columns=["Time Stamp", "Speed"], data=speed_list)
        test_speed.to_csv(
            "RawSpeed_" + scenario + "_" + str(cur_speed) + "kmh_" + str(times) + ".csv")
        test_SWA = pd.DataFrame(columns=["Time Stamp", "SWA"], data=angle_list)
        test_SWA.to_csv(
            "RawSWA_" + scenario + "_" + str(cur_speed) + "kmh_" + str(times) + ".csv")
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

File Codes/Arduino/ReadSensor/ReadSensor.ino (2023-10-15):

#include "Adafruit_MLX90393.h"

// Total 14 MLX90393 sensors
#define num 14 
Adafruit_MLX90393 sensor[num];

// CS pins of Teensy 4.1 MCU
int CS[num] = {A1, A0, A2, A3, A4, A5, A6, A7, A8, A9, A10, A11, A12, A13};
float data_array[num*3+1];

void setup()
{
  // baud rate: 921600
  Serial.begin(921600);
  /* Wait for serial on USB platforms. */
  while (!Serial)
  {
    delayMicroseconds(10);
  }
  delayMicroseconds(1000);
  for (int i = 0; i < num; ++i)
  {
    sensor[i] = Adafruit_MLX90393();
    // Use SPI protocol
    while (!sensor[i].begin_SPI(CS[i]))
    {
      Serial.print("No sensor ");
      Serial.print(i + 1);
      Serial.println(" found ... check your wiring?");
      delayMicroseconds(500);
    }
    
    // OSR: 0, Filter: 2
    while (!sensor[i].setOversampling(MLX90393_OSR_0))
    {
      Serial.print("Sensor ");
      Serial.print(i + 1);
      Serial.println(" reset OSR!");
    }
    delayMicroseconds(500);
    while (!sensor[i].setFilter(MLX90393_FILTER_2))
    {
      Serial.print("Sensor ");
      Serial.print(i + 1);
      Serial.println(" reset filter!");
    }
  }
}

void loop()
{ 
  int start_time = micros();
  for(int i = 0; i < num; ++i)
  {
    sensor[i].startSingleMeasurement();
  }
  // time for converting data
  delayMicroseconds(mlx90393_tconv[2][0] * 1000+100);
  for(int i = 0; i < num; ++i)
  {
    sensor[i].readMeasurement(&data_array[3*i], &data_array[3*i+1], &data_array[3*i+2]);
  }
  // record time interval
  data_array[3*num] = micros() - start_time;
  // write bytes to PC
  Serial.write((byte*)(data_array), 4*(3*num+1)); 
}

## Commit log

2023-10-07 update_left bar
    [LeftBar2.PcbDoc, LeftBar2.SchDoc, LeftBar3.PcbDoc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]
2023-10-08 update all pcb design
    [LeftBar1_PcbDoc.PcbDoc, LeftBar1_SchDoc.SchDoc, LeftBar2_PcbDoc.PcbDoc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]
2023-10-08 update arduino code
2023-10-09 update Arduino code (MLX90393 lib)
2023-10-09 Initialize BOM file
2023-10-10 add shell design
    [line_tag.stl]
2023-10-10 update the protective shell design
    [information_tag.stl]
2023-10-10 update readme of PCB design
2023-10-10 slightly change of the readme for PCBs
2023-10-15 update the METRO repo
    [information_tag.stl, line_tag.stl]
2023-10-15 update the metro repo, readme and bom file
    [sensor_array.xlsx]
